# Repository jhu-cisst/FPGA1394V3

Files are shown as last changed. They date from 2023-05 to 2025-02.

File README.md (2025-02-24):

# FPGA1394V3
Design files for FPGA1394V3 board in Altium Designer format. The design files for the previous
revisions, Rev 1.x and and Rev 2.x, are in [this repository](https://github.com/jhu-cisst/FPGA1394).

The Rev 3.x design is based on the Xilinx Zynq System on Chip (SoC), XC7Z020, which includes an
FPGA (PL) and dual-core ARM processor (PS). The previous versions (Rev 1.x and 2.x) were based on
the Xilinx Spartan 6 FPGA. In addition, the Rev 3.x design contains two Ethernet ports, as compared
to one in Rev 2.x and none in Rev 1.x.

* `FPGA3.PrjPCB`: Altium Designer project file
* `Snn.SchDoc`: schematics (Altium Designer format)
* `FPGA3.PcbDoc`: PCB layout (Altium Designer format)
* `FPGA1394V3-Schematics.pdf`: PDF of schematics
* `FPGA1394V3-BOM.xlsx`: Bill of Materials (Microsoft Excel format)
* `Panel`: Subdirectory with panel design, including PCB fabrication and assembly files
 
## Release Notes

* Rev 3.0: Prototype design (3 boards built), design files not released
* Rev 3.1: Initial Release, Build #9 (107 boards)
* Rev 3.2: Minor updates, Build #10 (65 boards)
  * Removed L9-10 (previously, 0 Ohm resistors) for RTL8211F DC/DC converter
  * Added C77-78 for soft-start of 3.3V and 5V power supplies
  * Added test points on underside of board for manufacturing test
  * Reduced openings for center pads on top side paste mask

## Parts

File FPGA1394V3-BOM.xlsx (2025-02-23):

 | IEEE-1394/Ethernet FPGA Board, Rev 3.2
 | Bill Of Materials
 | 2024-11-13
Revision: |  | 3.2
Seq | Qty. | Ref Des | Description | Package | Manufacturer | Notes | Manufacturer Part # | Distributor | Distributor Part # | Avcon Part # | Est. Unit $ | Extended Cost
1 | 5 | C1-5 | CAP 22pF, 5%, 50V, NPO, 0402 | 0402 | Generic | 2
2 | 2 | C6-7 | CAP, 220pF, 5%, 50V, NPO, 0603 | 0603 | Generic | 2 | C0603C221J5GACTU | Digikey | 399-1066-1-ND | 022-2216-61/603 | 0.02 | 0.05
3 | 2 | C8-9 | CAP, 0.01uF, 10%, 16V, X7R, 0402 | 0402 | Generic | 2
4 | 21 | C10-30 | CAP, 0.1uF, 10%, 16V, X7R, 0402 | 0402 | Generic | 2 | GRM155R71C104KA88D
5 | 10 | C31-40 | CAP, 1.0uF, 10%, 10V, X7S, 0402 | 0402 | Generic | 2 | GCM155C71A105KE38D |  | 490-13409-1-ND
6 | 5 | C41-45 | CAP, 22uF, 20%, 25V, X5R, 0805 | 0805 | Murata | 2 | GRM21BR61E226ME44L |  | 490-10749-6-ND |  | 0.14 | 0.68
7 | 13 | C46-58 | CAP, 220uF, 20%, 4V, X6S, 1206 | 1206 | Murata | 2 | GRM31CC80G227ME11L |  | 490-13250-6-ND |  | 0.43 | 5.62
8 | 2 | C59-60 | CAP, 10uF, 20%, 50V, X7S, 1210 | 1210 | Murata | 2 | GCM32EC71H106KA03L |  | 490-14536-6-ND |  | 0.59 | 1.19
9 | 5 | C61-65 | CAP, 100uF, 20%, 10V, X5R, 1210 | 1210 | Samsung | 2 | CL32A107MPVNNNE | Digikey | 1276-3364-1-ND | 022-1071-81/121 | 0.65 | 3.24
10 | 2 | C66-67 | CAP, 220uF, 20%, 6.3V, X5R, 1210 | 1210 | Samsung | 2 | CL32A227MQVNNNE | Digikey | 1276-3375-1-ND | 022-2270-81/121 | 1.22 | 2.44
11 | 2 | C68-69 | CAP, 33uF 10%, 50V, Conductive Polymer "KO Cap" | CAP-D | Kemet | NS | T521X336M050ATE075 | Digikey | 399-11721-1-ND | 022-3366-81SM | 4.80 | 9.60
12 | 2 | C70-71 | CAP, 330uF 10%, 10V, Conductive Polymer "KO Cap" | CAP-D | Kemet | NS | T520Y337M010ATE015 | Digikey | 399-10362-1-ND | 022-3371-81SM | 3.24 | 6.48
13 | 2 | C72-73 | CAP, 470uF 10%, 6.3V, Conductive Polymer "KO Cap" | CAP-D | Kemet | NS | T520D477M006ATE025 | Digikey | 399-4985-1-ND | 022-4770-71SMD | 1.35 | 2.70
14 | 1 | C74 | CAP, 680uF 10%, 2.5V, Conductive Polymer "KO Cap" | CAP-D | Kemet | NS | T520D687M2R5ATE015 | Digikey | 399-4065-1-ND | 022-6870-81SMD | 1.31 | 1.31
15 | 2 | C75-76 | CAP, 1000uF, 20%, 2.5V, 5mOhm | CAP-D | Panasonic | 2 | ETPF1000M5H |  | P16642DKR-ND |  | 2.38 | 4.75
16 | 2 | C77-78 | CAP, 4700pF, 10%, 16V, X7R, 0402 | 0402 | Generic | 2
17 | 75 | CB1-75 | CAP, 0.1uF, 20%, 6.3V, X6S, 0201 | 0201 | Generic | 2 | GRM033C80J104KE15D |  | 490-10390-6-ND
18 | 40 | CB76-115 | CAP, 0.47uF, 20%, 16V, X7R, 0402 | 0402 | Generic | 2 | GCM155C71A474KE36D |  | 490-14427-1-ND
19 | 25 | CB116-140 | CAP, 10uF, 20%, 16V, X6S, 0603 | 0603 |  | 2 | GRM188C81C106MA73D |  | 490-7198-6-ND |  | 0.07 | 1.82
20 | 1 | D1 | TVS, 16V Bidirectional, SMCJ16C | DIODE-SMC |  | 2 | SMCJ16CA |  | SMCJ16CALFCT-ND |  | 0.41 | 0.41
21 | 3 | D2-4 | LED, Green, RA, 0805 | 0805 | Broadcom | 2 | HSME-C170 | Digikey | 516-3542-1-ND | 024-6176-805 | 0.32 | 0.95
22 | 8 | D5-12 | DIODE, BAV99T, Dual/Serial, 70V, 85mA | SOT-523 | Diodes Inc. | 2 | BAV99T-7-F | Digikey | BAV99T-FDICT-ND | 024-0118-SM | 0.04 | 0.34
23 | 2 | J1-2 | CONN, Socket, 2x22 Pos, Vertical, 2MM | TH | Samtec | 2 | ESQT-122-02-L-D-560 | Samtec | ESQT-122-02-L-D-560 | 026-0844-00 | 5.72 | 11.44
24 | 2 | J3-4 | CONN, IEEE-1394, 6-Pin, R/A | Firewire6-RA | 3M | NS, 4 | 3E106-2230KV | Digikey | 3M9423-ND | 026-1139-00 | 3.34 | 6.69
25 | 1 | J5 | CONN, MicroSDCARD, ST12S010 | SM | JAE | NS | ST12S010VBAR1800 |  | 670-3034-1-ND |  | 2.12 | 2.12
26 | 1 | J6 | CONN, Header, 2 Pos, Vertical 0.100 | HDR-2x1-100 | Tyco | 2 | 640456-2 | Digikey | A1921-ND | 026-0080-00 | 0.09 | 0.09
27 | 1 | J7 | CONN, Header, 2x7 Pos, Vertical, Polarized, 2MM | HDR-7x2-2MM | FCI | 2 | 98414-G06-14LF | Digikey | 609-2576-ND | 026-0847-00
28 | 1 | J8 | CONN, Dual RJ-45 With Transformer 10/100/1000 | TH | Pulse |  | JXD0-2015NL | Digikey | 1840-1011-ND |  | 11.40 | 11.40
29 | 1 | J9 | CONN, RA, DF-11, 6-pin | DF-11-6-RA | Hirose |  | DF11-6DP-2DS(24) | Digikey | H10245-ND |  | 0.43 | 0.43
30 | 1 | J10 | CONN, Header, 6 Pos, Vert 0.1" pitch, 0.23" - 0.318" ht | HDR-6x1-100 | AMP | 2 | 5-146280-6 | Digikey | A121372-ND | 029-0507-06 |  | 0.00
31 | 1 | L1 | INDUCTOR, 1.5uH, 13A, XGL5050 | XGL5050 | Coilcraft | NS | XGL5050-152MEC |  |  |  | 2.26 | 2.26
32 | 1 | L2 | INDUCTOR, 1.2uH, 15A, XGL5050 | XGL5050 | Coilcraft | NS | XGL5050-122MEC |  |  |  | 2.26 | 2.26
33 | 1 | L3 | INDUCTOR, 0.68uH, 10A, XGL4040 | XGL4040 | Coilcraft | NS | XGL4040-681MEC |  |  |  | 1.79 | 1.79
34 | 2 | L4-5 | INDUCTOR, 1.5uH, 8A, XGL4040 | XGL4040 | Coilcraft | NS | XGL4040-152MEC |  |  |  | 1.34 | 2.68
35 | 2 | L6-7 | INDUCTOR, 3.3uH, 0.9A, EPL2014 | EPL2014 | Coilcraft | NS | EPL2014-332MLC |  |  |  | 0.26 | 0.52
36 | 1 | L8 | FERRITE, 500mA, 150mOhm, 600 Ohm @ 100MHz | 0603 | Murata | 2 | BLM18KG601BH1D | Digikey | 490-14032-1-ND |  | 0.04 | 0.04
37 | 4 | L11-14 | FERRITE BEAD, 2A, 50mOhm, 120 Ohm @ 100MHz | 0402 | Murata | 2 | BLM15PX121SN1D | Digikey | 490-9656-1-ND |  | 0.03 | 0.11
38 | 2 | L15-16 | FERRITE BEAD, 50 Ohm/10 mOhm, 6A | 1206 | Laird | 2 | HI1206T500R-10 | Digikey | 240-2412-1-ND | 023-0431-1206 | 0.06 | 0.11
39 | 2 | Q1-2 | MOSFET, N-Chan, 20V, Si7108 | PowerPack-1212 | Vishay | 2 | SI7108DN-T1-GE3 | Digikey | SI7108DN-T1-GE3CT-ND | 024-2189-SM | 1.40 | 2.81
40 | 1 | Q3 | MOSFET, P-Chan, 40V, Si7611 | PowerPack-1212 | Vishay | 2 | SI7611DN-T1-GE3 | Digikey | SI7611DN-T1-GE3CT-ND | 024-2193-SM | 0.70 | 0.70
41 | 2 | Q4-5 | MOSFET, Dual N-Chan, 20V 250mA | SC70-6 | NXP | 2 | PMG370XN,115 |  |  | 024-2190-SM | 0.07 | 0.13
42 | 1 | Q6 | TRANSISTOR, PNP, 1A, 20V, DCX69-16 | SOT-89 | Diodes Inc. | 2 | DCX69-16-13 | Digikey | DCX69-16DICT-ND | 024-1036-SM | 0.35 | 0.35
43 | 8 | R1-8 | RES, 49.9 Ohm, 1%, 1/20W, 0201 | 0201 | Generic | 2
44 | 1 | R9 | RES, 4.99, 1% 1/16W | 0402 | Generic | 2
45 | 23 | R10-32 | RES, 40.2, 1% 1/16W | 0402 | Generic | 2
46 | 3 | R33-35 | RES, 80.6, 1% 1/16W | 0402 | Generic | 2
47 | 4 | R36-39 | RES, 100, 1% 1/16W | 0402 | Generic | 2
48 | 6 | R40-45 | RES, 240, 1% 1/16W | 0402 | Generic | 2
49 | 10 | R46-55 | RES, 499, 1% 1/16W | 0402 | Generic | 2
50 | 5 | R56-60 | RES, 1.00K, 1% 1/16W | 0402 | Generic | 2
51 | 0 | R60A | Do Not Install | 0402 |  | 3
52 | 4 | R61-64 | RES, 1.50K, 1% 1/16W | 0402 | Generic | 2
53 | 2 | R65-66 | RES, 2.49K, 1% 1/16W | 0402 | Generic | 2
54 | 11 | R67-77 | RES, 4.99K, 1% 1/16W | 0402 | Generic | 2
55 | 2 | R78-79 | RES, 6.34K, 1% 1/16W | 0402 | Generic | 2
56 | 2 | R80-81 | RES, 13.3K, 1% 1/16W | 0402 | Generic | 2
57 | 11 | R82-92 | RES, 20.0K, 1% 1/16W | 0402 | Generic | 2
58 | 1 | R93 | RES, 31.6K, 1% 1/16W | 0402 | Generic | 2
59 | 1 | R94 | RES, 162K, 1% 1/16W | 0402 | Generic | 2
60 | 2 | R95-96 | RES, 301K, 1% 1/16W | 0402 | Generic | 2
61 | 1 | R97 | RES, 22.1K, 0.1%, 1/16W, 0402 | 0402 |  | 2 | CPF-A-0402B22K1E |  | 1712-CPF-A-0402B22K1ECT-ND |  | 0.21 | 0.21
62 | 7 | R98-104 | RES, 100K, 0.1%, 1/16W, 0402 | 0402 |  | 2 | CPF0402B100KE |  | A119916CT-ND |  | 0.12 | 0.82
63 | 1 | R105 | RES, 115K, 0.1%, 1/16W, 0402 | 0402 |  | 2 | RP73PF1E115KBTD |  | A127517CT-ND |  | 0.62 | 0.62
64 | 2 | R106-107 | RES, 150K, 0.1%, 1/16W, 0402 | 0402 |  | 2 | CPF0402B150KE |  | A119924CT-ND |  | 0.20 | 0.41
65 | 1 | R108 | RES, 200K, 0.1%, 1/16W, 0402 | 0402 |  | 2 | CPF0402B200KE |  | A119933CT-ND |  | 0.20 | 0.20
66 | 8 | R109-116 | RES, 56.0, 0.5%, 1/10W, 0603 | 0603 | Susumu | 2 | RR0816Q-560-D | Digikey | RR08Q56DCT-ND | 020-5607-41/603 | 0.02 | 0.19
67 | 2 | R117-118 | RES, 0.015, 1%, 1/2W, 1206 | 1206 |  | 2 | CSR1206FK15L0 | Digikey | CSR1206FK15L0CT-ND |  | 0.23 | 0.47
68 | 2 | RN1-2 | RES ARRAY, 4.7K, 4 DIS, 5%, SM 0.032 | R-SM-8/32 | CTS | 2 | 742C083472JPTR | Digikey | 742C083472JPCT-ND | 020-4701-61RA | 0.06 | 0.12
69 | 1 | SW1 | SWITCH, Rotary, Hex | TH | Grayhill | 2 | 94HAB16T | Digikey | GH7255-ND | 029-0458-00 | 2.48 | 2.48
70 | 1 | U1 | IS, SOC, XC7Z020-CLG400 | BGA-400-08mm | Xilinx | 5 | XC7Z020-sCLG400t | Digikey | 122-1848-ND |  | 180.70 | 180.70
71 | 2 | U2-3 | IC, DRAM, 256M x 16, MT41K256M16 | BGA-96-14x8mm | Micron | NS | MT41K256M16TW-107:P | Digikey | 557-1792-ND |  | 8.64 | 17.29
72 | 1 | U4 | IC, 128MBit Quad SPI Flash PROM, W25Q128JVSIQ | SOL-8 | Winbond | NS | W25Q128JVSIQ |  | W25Q128JVSIQ-ND |  | 1.48 | 1.48
73 | 1 | U5 | IC, IEEE-1394 Physical Layer, TSB41AB2 | PQFP-65 | TI |  | TSB41AB2PAP | Digikey | 296-11076-ND | 024-9309-SM | 5.55 | 5.55
74 | 1 | U6 | IC, Shunt Regulator, 1.24V, 70mA, TLVH431 | SC70-6 | TI |  | TLVH431ACDCKT | Digikey | 296-32425-1 | 024-2415-SM | 0.68 | 0.68
75 | 1 | U7 | IC, Oscillator, 24.576MHz, 50PPM, 3.3V | OSC-3x5MM | AVX | 2 | KC5032A24.5760CM0E00 | Digikey | 1253-1042-1-ND | 029-0459-SM | 1.31 | 1.31
76 | 1 | U8 | IC, Bidirectional Voltage Translator, TXS0101 | SC70-6 | TI | 2 | TXS0101DCK | Digikey | 296-22864-1-ND |  | 0.27 | 0.27
77 | 1 | U9 | IC, Dual Buffer, 74AUP2G17 | SC70-6 | NXP | 2 | 74AUP2G17GW,125 | Digikey | 1727-6878-1-ND |  | 0.22 | 0.22
78 | 2 | U10-11 | IC, Ethernet PHY, RTL8211F | QFN-40-5MM | Realtek |  | RTL8211F-CG |  |  |  | 3.59 | 7.18
79 | 2 | U12-13 | IC, Hot Swap Controller with retry, LTC4210-1 | SOT-23-6 | Linear Tech | 1 | LTC4210-1CS6#PBF | Linear Tech | LTC4210-1CS6#PBF | 024-3782-SM | 3.39 | 6.78
80 | 1 | U14 | IC, 4 Phase Spread Spectrum Clock, LTC6902 | MSOP-10 | Linear Tech | 1 | LTC6902CMS#TRPBFCT | Linear Tech | LTC6902CMS#TRPBFCT | 024-2754-SM | 4.28 | 4.28
81 | 1 | U15 | IC, Quad Step-Down DC-DC Converter, LTC3644 | BGA-36-08mm | Linear Tech | 1 | LTC3644EY#PBF | Digikey | 161-LTC3644EY#PBF-ND |  | 5.62 | 5.62
82 | 1 | U16 | IC, Dual Step-Down DC-DC Converter, LTC3636 | QFN-28-LTC3636 | Linear Tech | 1 | LTC3636IUFD-1#PBF | Digikey | LTC3636IUFD-1#PBF-ND |  | 8.86 | 8.86
83 | 1 | U17 | IC, Quad Voltage Monitor, LTC2908-B1 | SOT-23-8 | Linear Tech | 1 | LTC2908CTS8-B1#TRMPBF |  | LTC2908CTS8-B1#TRMPBFCT-ND |  | 5.09 | 5.09
84 | 1 | U18 | IC, DDR Termination Power Supply, LP2998 | SO-8 | TI |  | LP2998QMRX/NOPB | Digikey | 296-49242-1-ND |  | 1.46 | 1.46
85 | 1 | U19 | IC, Crystal Oscillator, 25.00MHz | OSC-2x2.5mm | ECS | 2 | ECS-2520MVQ-250-BP-TR | Digikey | 50-ECS-2520MVQ-250-BP-CT-ND | 024-9372-SM | 1.11 | 1.11
86 | 1 | U20 | IC, Crystal Oscillator, 33.33MHz | OSC-2x2.5mm | Abracon | 2 | ASDDV-33.3333MHZ-LC-T |  | 535-ASDDV-33.3333MHZ-LC-TCT |  | 1.16 | 1.16
87 | 1 |  | PCB, IEEE-1394/Ethernet FPGA Controller, Rev 3.1 |  |  |  |  |  |  |  | 25.00 | 25.00
 | 402 |  |  |  |  |  |  |  |  | Estimated Total Cost: |  | $367.07
Notes:
 | ● | Text highlighted in red is highlighted to draw attention to the value/parameter and does not carry any special meaning.
 | ● | Component prices shown are the best guess at the time of updating this BOM, assuming Qty ~100 boards. Actual prices may be higher or lower depending upon a number of factors.
 | ● | Unless specified otherwise, the only substitutions allowed are substituting identical part number parts from a different manufacturer.
 | NS | No substitutions of any kind are allowed.
 | 1 | For Linear Tech parts, it is acceptable to substitute I (industrial temp), E (extended temp) or H (high temp) rated parts.
 |  | The suffixes "TRM" and "TR" signify tape and reel styles. Parts with suffix TRM, suffix TR can be substituted as needed.
 |  | Other than as specified above, no other substitutions are allowed.
 | 2 | Any component in an identical package that meets or exceeds all the parameters specified in the description can be substituted.
 | 3 | Either R60 or R60A can be installed.
 | 4 | Another approved part is TE Connectivity AMP 5787956-1 (Digikey P/N A114040-ND)
 | 5 | XC7Z020-sCLG400t, where s (speed grade) can be 2 or 3 and t (temperature grade) can be C, I or E

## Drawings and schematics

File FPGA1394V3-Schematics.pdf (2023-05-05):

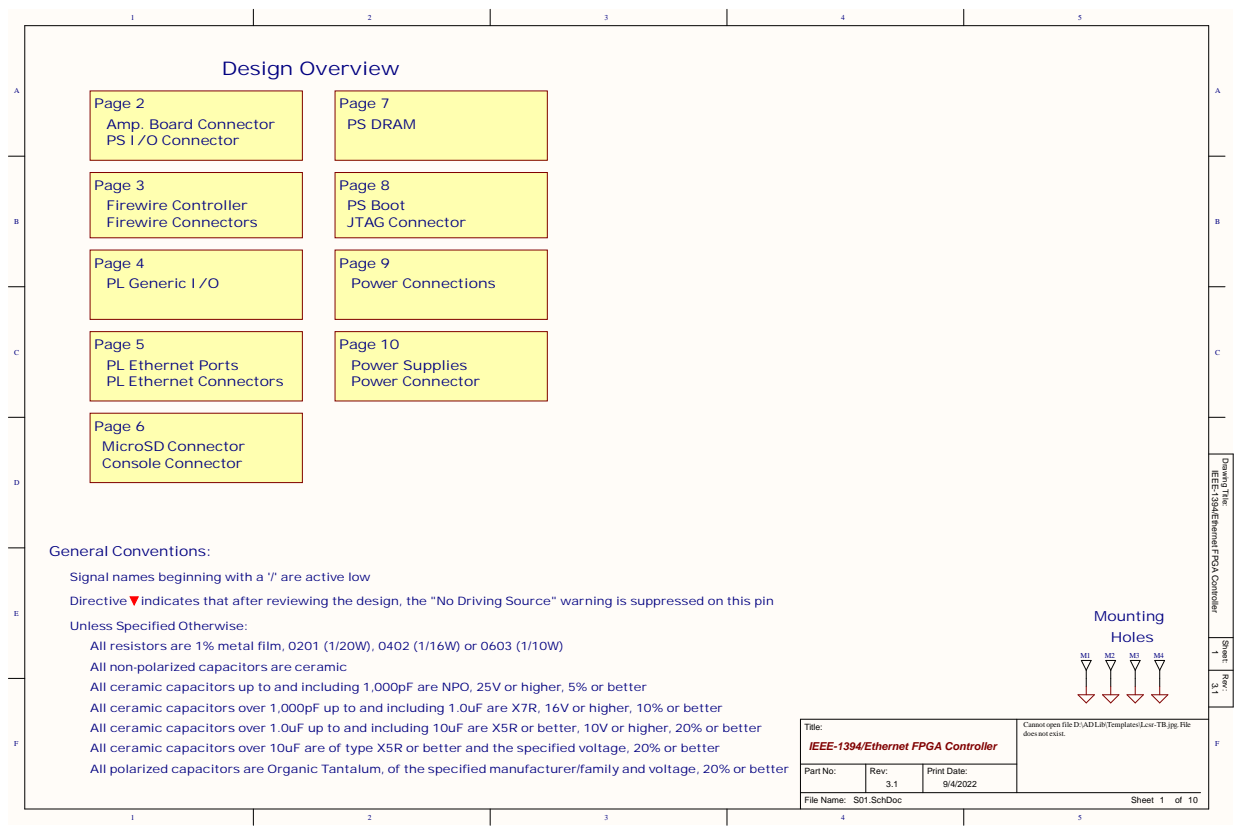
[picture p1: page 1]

Drawing Title: Rev: Sheet:

1 IEEE-1394/Ethernet FPGA Controller 3.1

Title: IEEE-1394/E thernet FP GA Controller | Sheet 1 o f 10

File Name: S01. | S chDoc

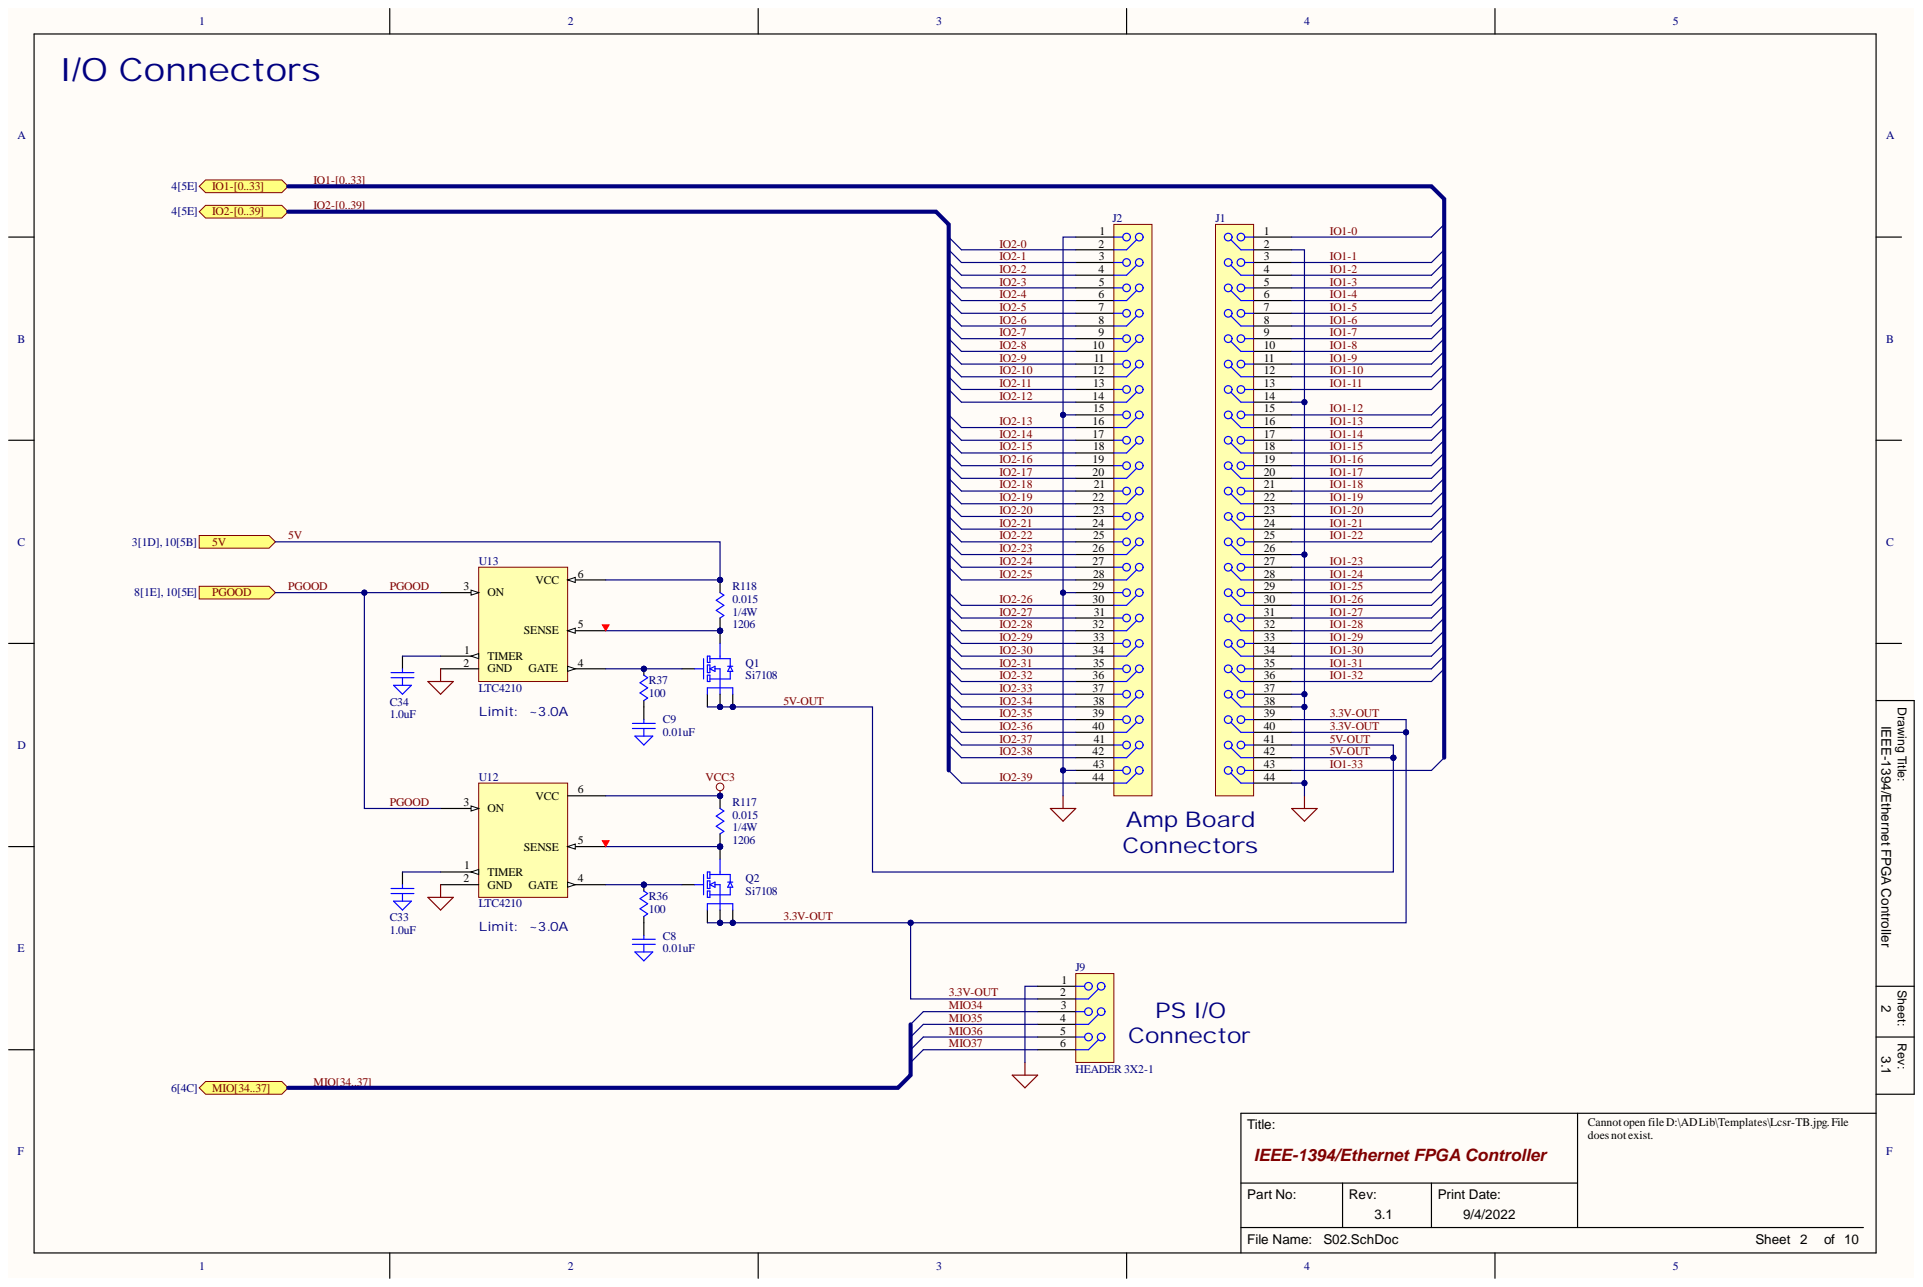
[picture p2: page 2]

Drawing Title: Rev: Sheet:

40 | 3.3V-OUT
41 | 5V-OUT
42 | | 5V-OUT
43 | | IO1-33
44

2 IEEE-1394/Ethernet FPGA Controller 3.1

Cannot open file D:\ADLib\Templates\Lcsr-TB.jpg. File
does not exist.

Title: IEEE-1394/Ethernet FPGA Controller | Sheet 2 of 10

File Name: S02.SchDoc

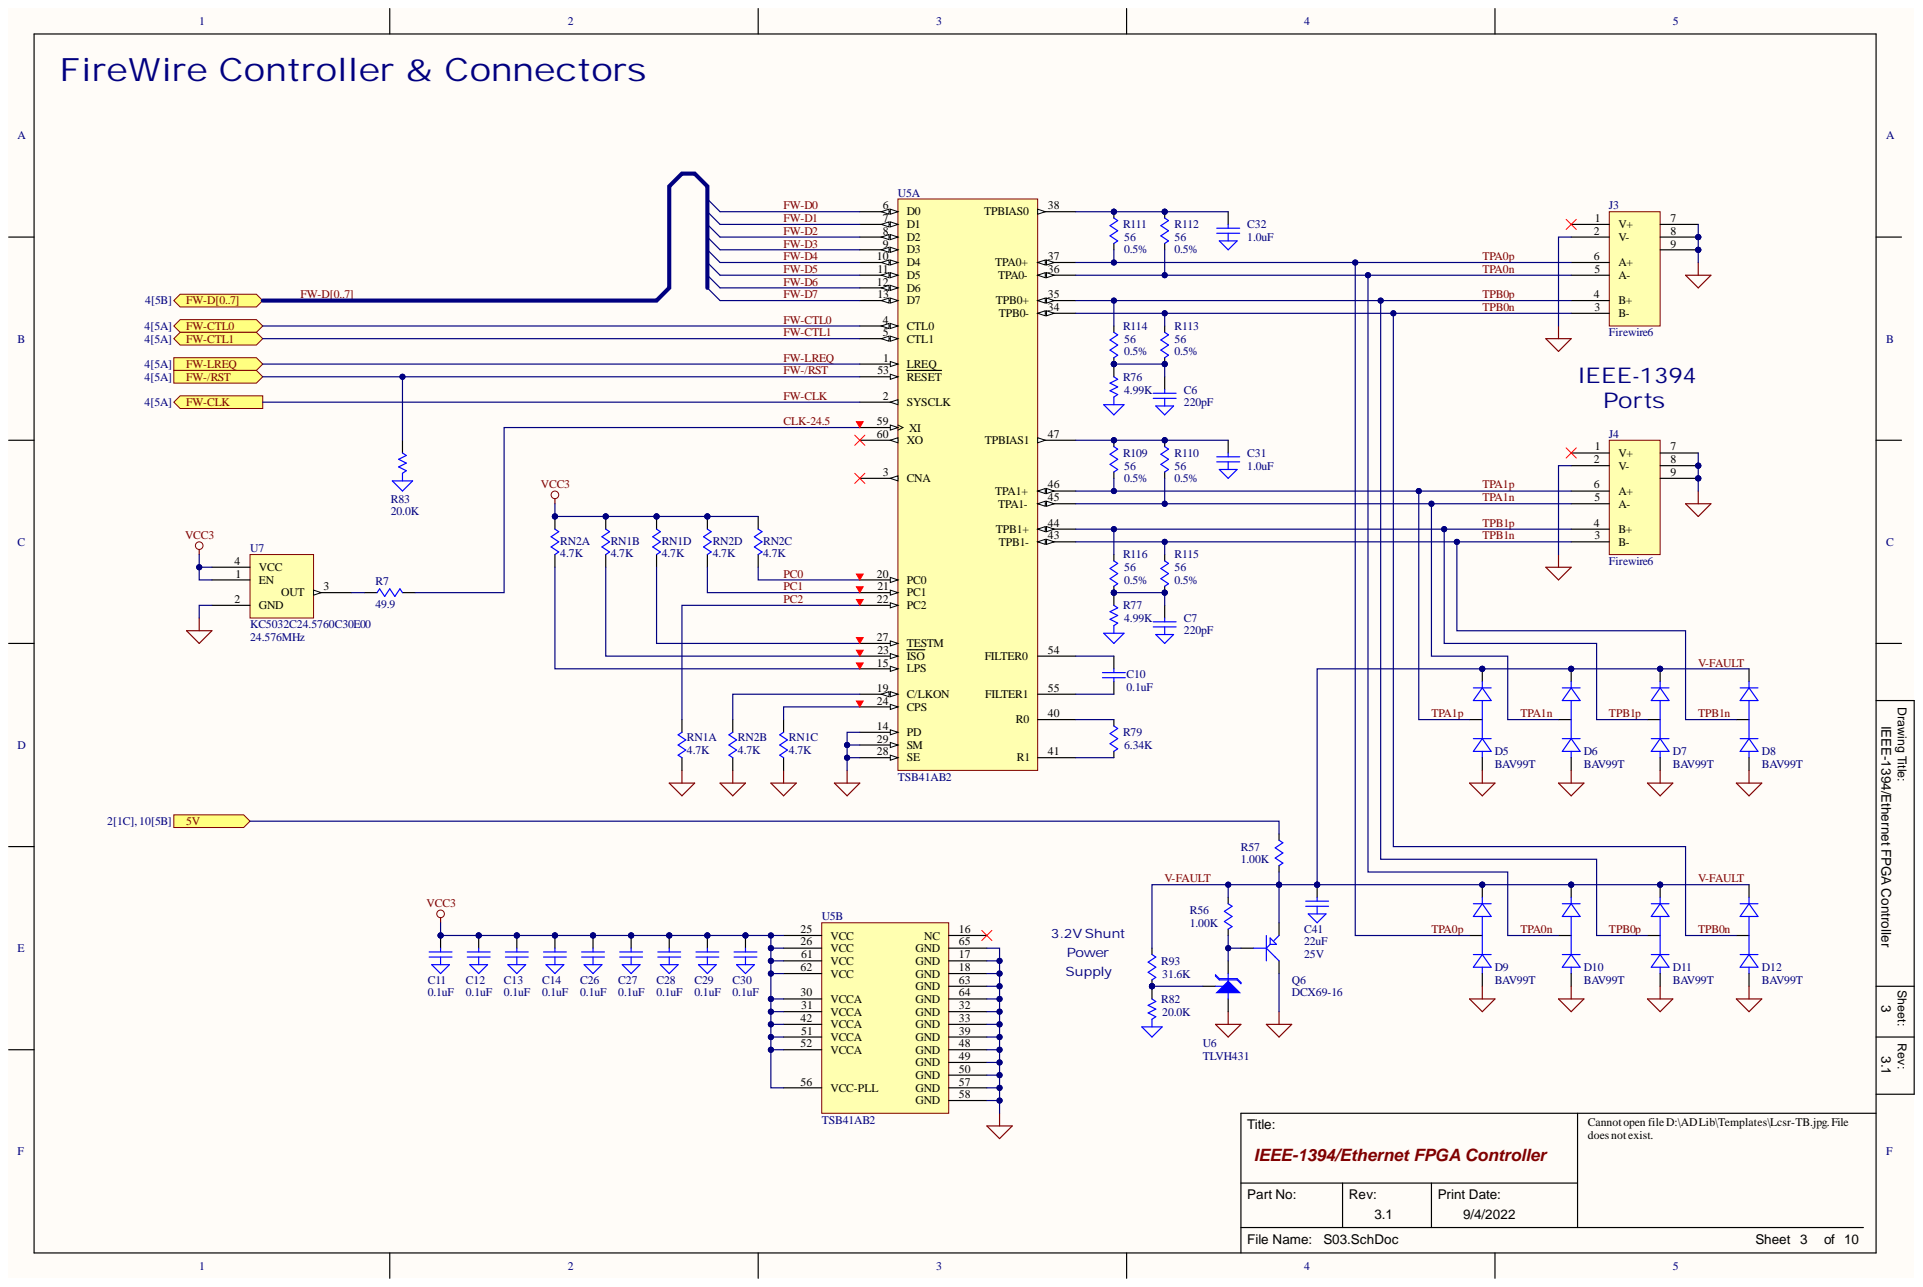
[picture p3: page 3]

TPB 0p | 4
TPB 0n | 3 | B + B -

TPB 1 p | 4
TPB 1 n | 3 | B -

Drawing Title: Rev: Sheet:

3 IEEE-1394/Ethernet FPGA Controller 3.1

Title: IEEE-1394/E thernet FP GA Controller | Sheet 3 o f 10

File Name: S03. | S chDoc

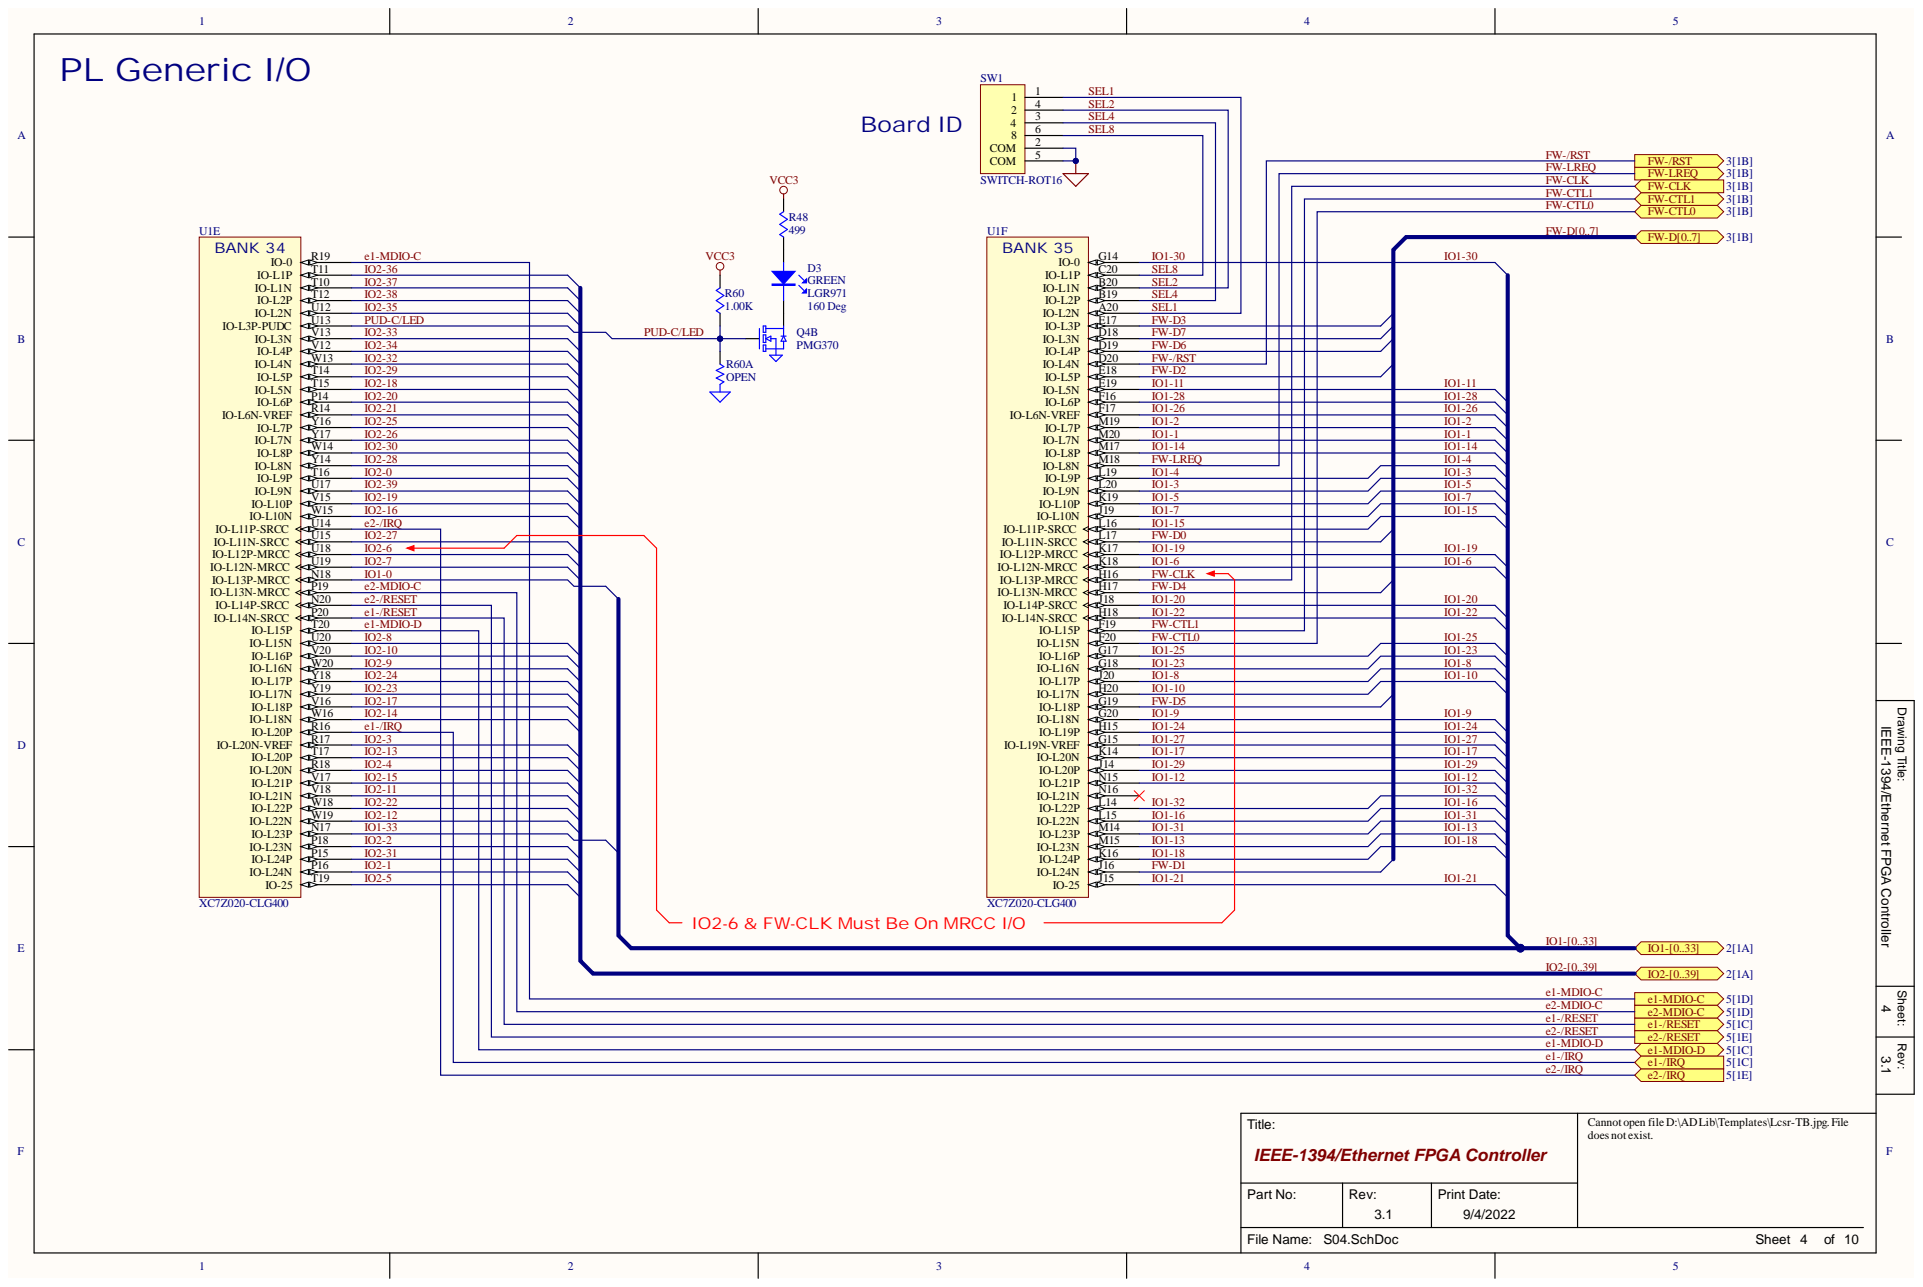
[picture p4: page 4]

4 | SE L 2
3 | SE L

FW -C T L 1
FW -C T L0

BANK 35 | O -0

T 1 1 T10 T12 U12 U13 | R60A OPEN I O2-29 I O2-18 I O2-20 I O2-21 I O2-25 I O2-26 I O2-30 I O2-28 I O2-0 I O2-39 I O2-19 I O2-16 e2-/ I RQ | I O -I O -I O -I O -I O -I O -I O -I O -L6N -V I O -I O -I O -I O -I O -I O -I O -I O -I O -L 11P-SR | L1P | C20 | SE L 8

L1N | B20 | SE L 2
L2P | A20 | SE L 1

N20 | e2-/ R E S ET | I O -L14P-SR CC | J 1 8 | I O1-20 | I O1-20
0 | e1-/ R E S ET | I O -L14N -SR CC | H18 | I O1-22 | I O1-22
T20 | e1-M D I O -D | L15P I O - | F1 9 | FW -C T L 1
U20 V20 0 Y18 Y19 V16 6 R16 | I O2-8 I O2-10 I O2-9 I O2-24 I O2-23 I O2-17 I O2-14 e1-/ I RQ | L15N I O -I O -L16P I O -L16N I O -L17P I O -L17N I O -L18P I O -L18N I O -L19P | F2 0 | FW -C T L0 | I O1-25

Drawing Title: Rev: Sheet:

4 IEEE-1394/Ethernet FPGA Controller 3.1

Title: IEEE-1394/E thernet FP GA Controller | Sheet 4 o f 10

File Name: S04. | S chDoc

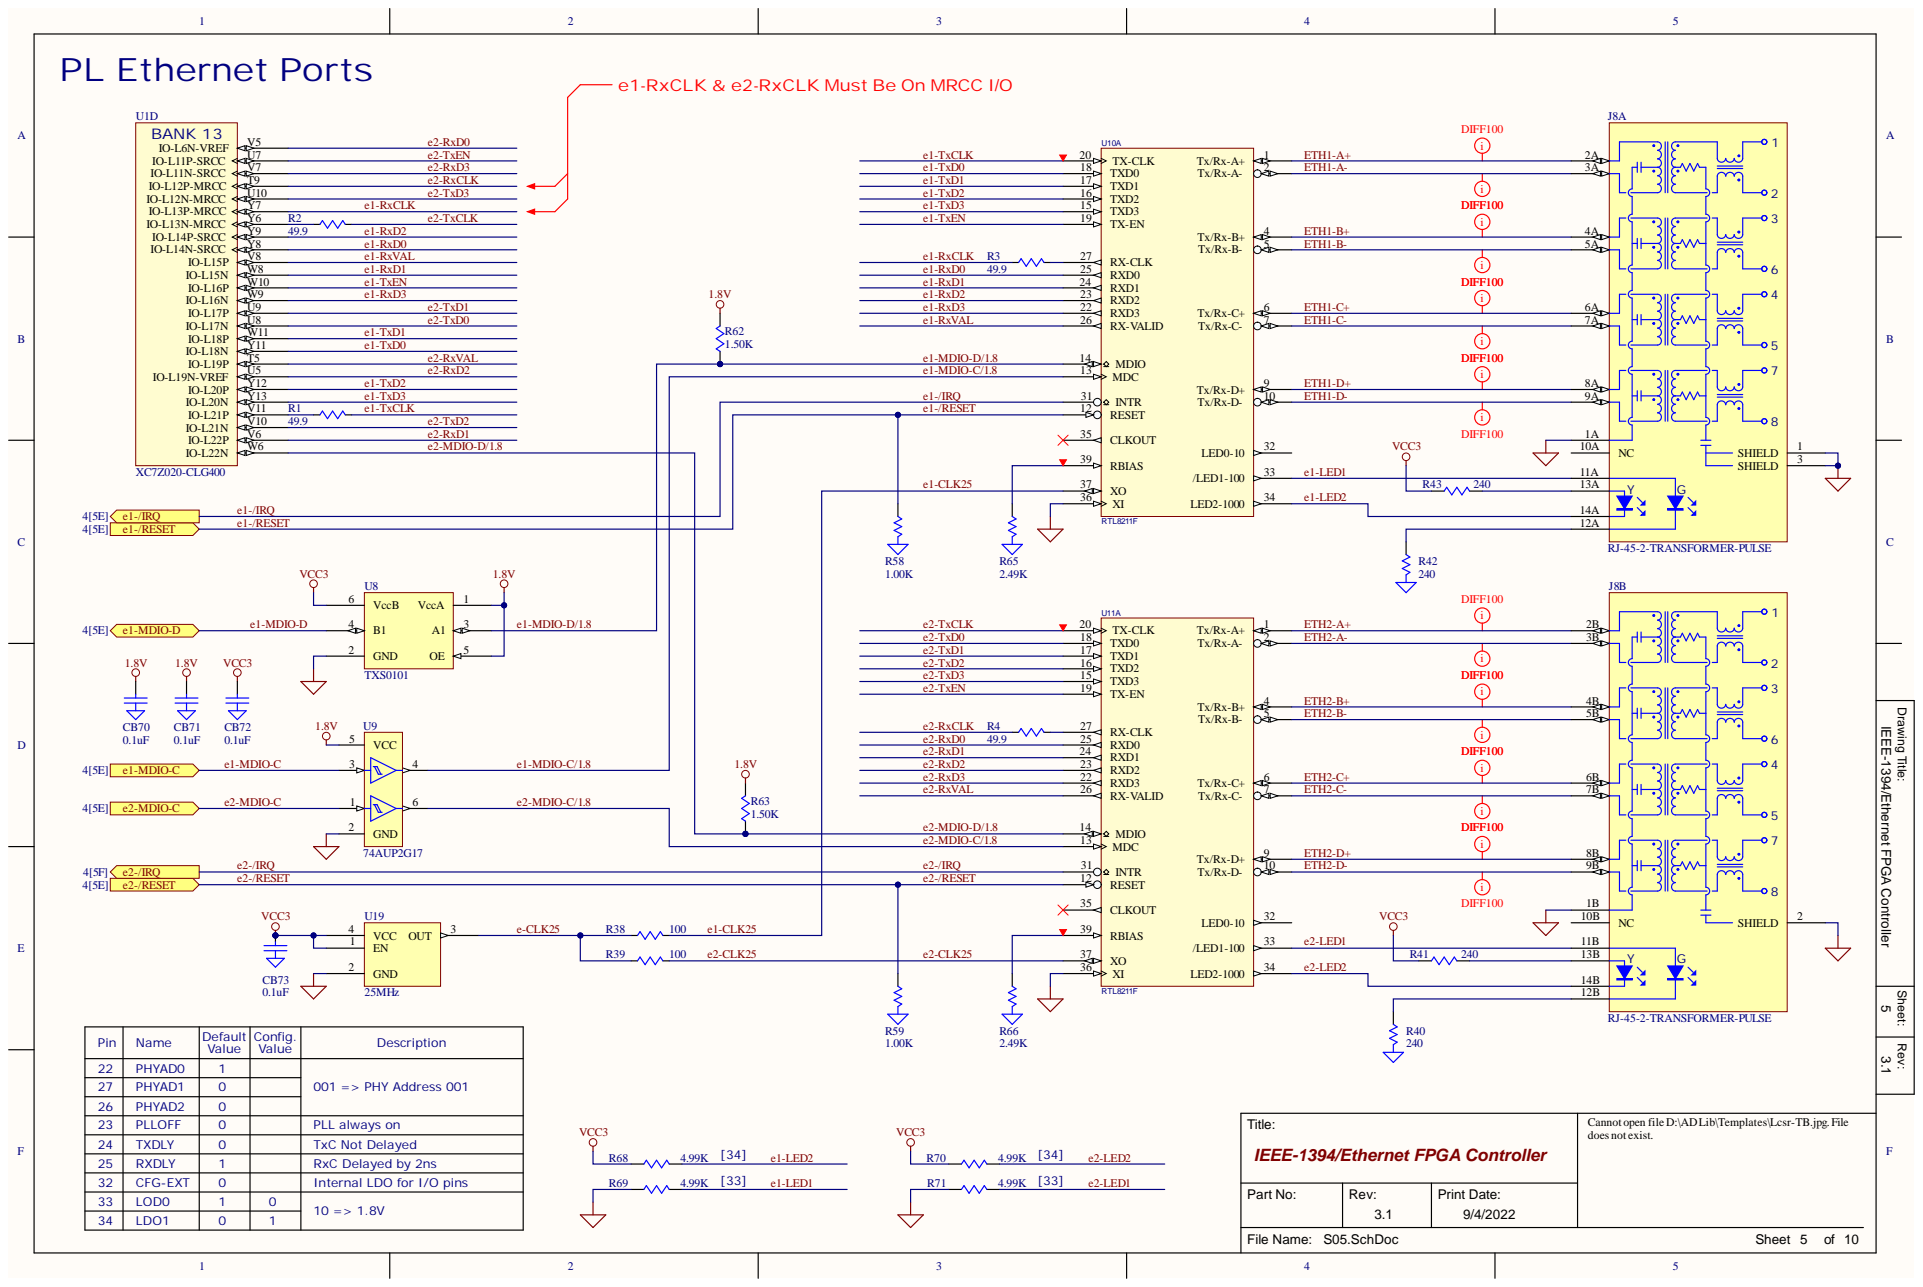
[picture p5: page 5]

e1-RxCLK & e2-RxCLK Must Be On MRCC I/O

XO 37
XI 36

e1-LED2

e1-/RESET | | | | | | 12A

VCC3 U8 | | 1.8V | R58 R65 1.00K 2.49K e2-TxCLK

VccA | A1 | 1 VccB 6 3 B1 4

Drawing Title: Rev: Sheet:

5 IEEE-1394/Ethernet FPGA Controller 3.1

R39 | 100 e2-CLK25 | e2-CLK25 | XO 37

Pin | Name | Default Value | Config. Value | Description

22 | PHYAD0 | 1 | | 001 => PHY Address 001
27 | PHYAD1 | 0
26 | PHYAD2 | 0

Cannot open file D:\ADLib\Templates\Lcsr-TB.jpg. File
does not exist.

Title:
IEEE-1394/Ethernet FPGA Controller

24 | TXDLY | 0 | | TxC Not Delayed
25 | RXDLY | 1 | | RxC Delayed by 2ns
32 | CFG-EXT | 0 | | Internal LDO for I/O pins
33 | LOD0 | 1 | 0 | 10 => 1.8V
34 | LDO1 | 0 | 1

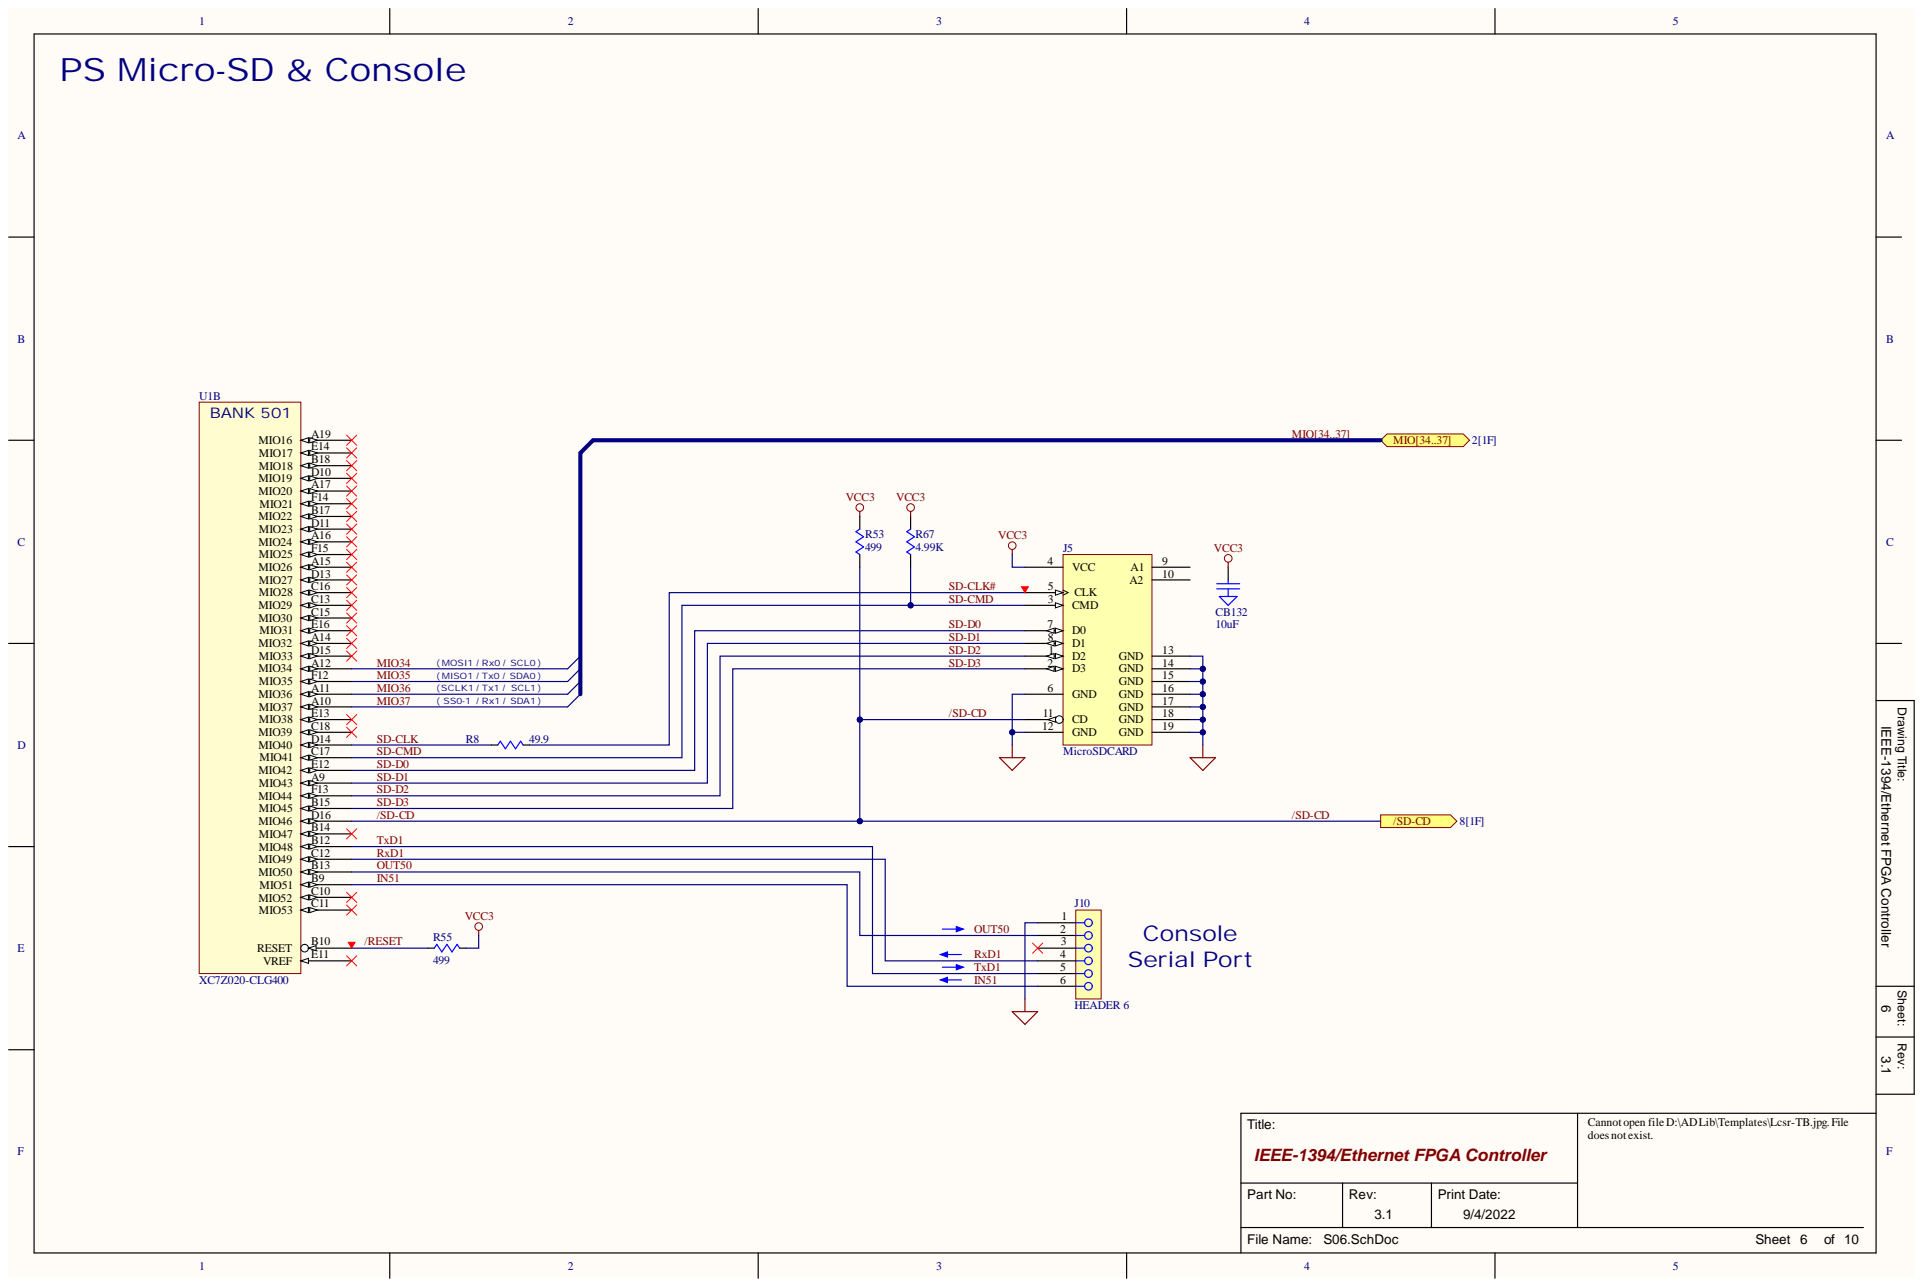
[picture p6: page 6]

SD -D0 | 7
SD -D 1 | 8
SD -D2 | 1

Drawing Title: Rev: Sheet:

6 IEEE-1394/Ethernet FPGA Controller 3.1

SD -D0
SD -D 1
SD -D2
SD -D 3

RxD 1
O U T50

RxD 1 | 123456

Title: IEEE-1394/E thernet FP GA Controller | Sheet 6 o f 10

File Name: S06. | S chDoc

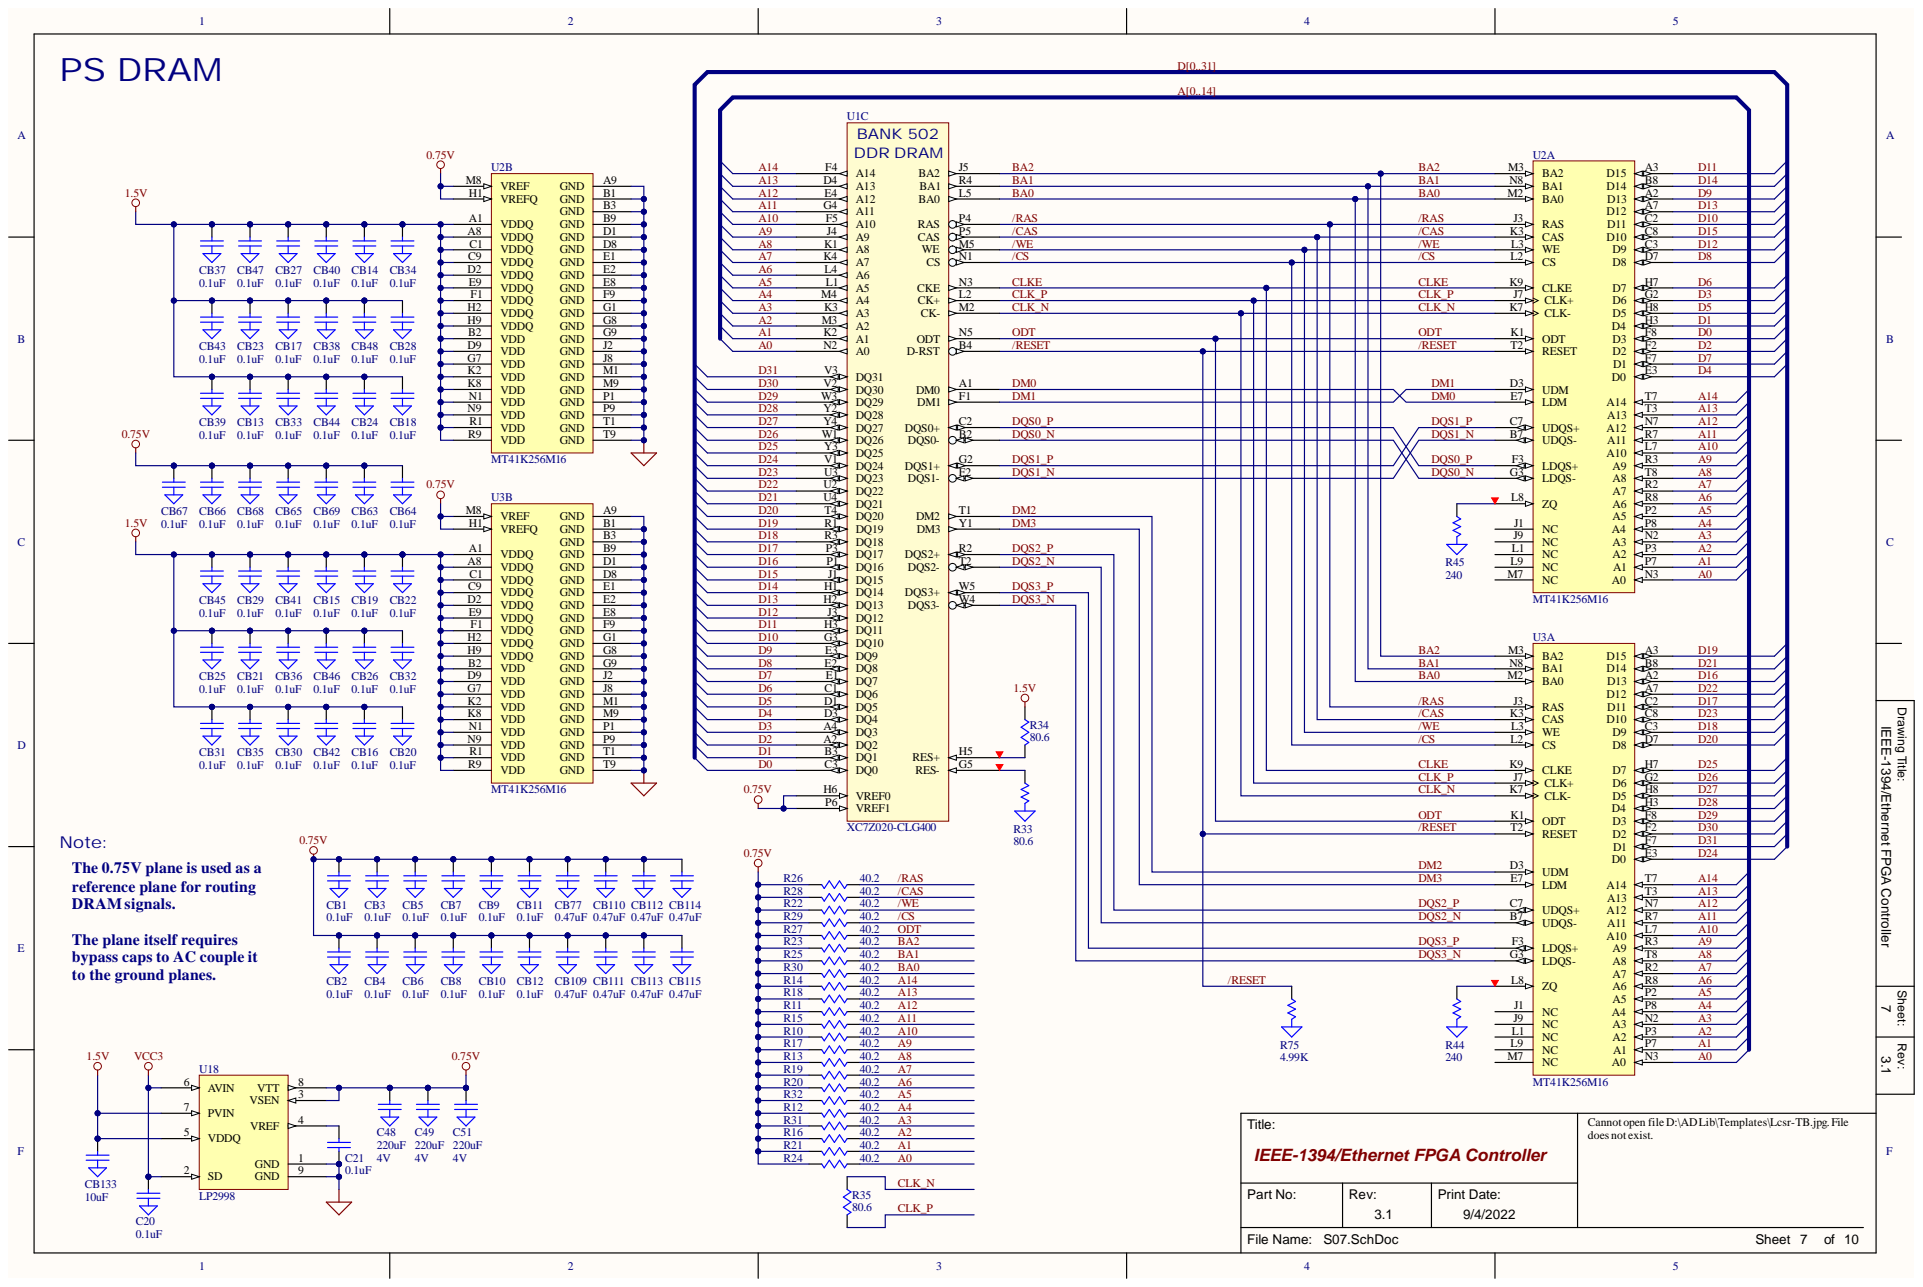
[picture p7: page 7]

K 2 | M 1
K 8 | M 9

R 1 | T 1
R 9 | T 9

Drawing Title: Rev: Sheet:

7 IEEE-1394/Ethernet FPGA Controller 3.1

D M 2 | D 3
D M 3 | E 7

ane itself requires
The pl
bypa
to the ground pl

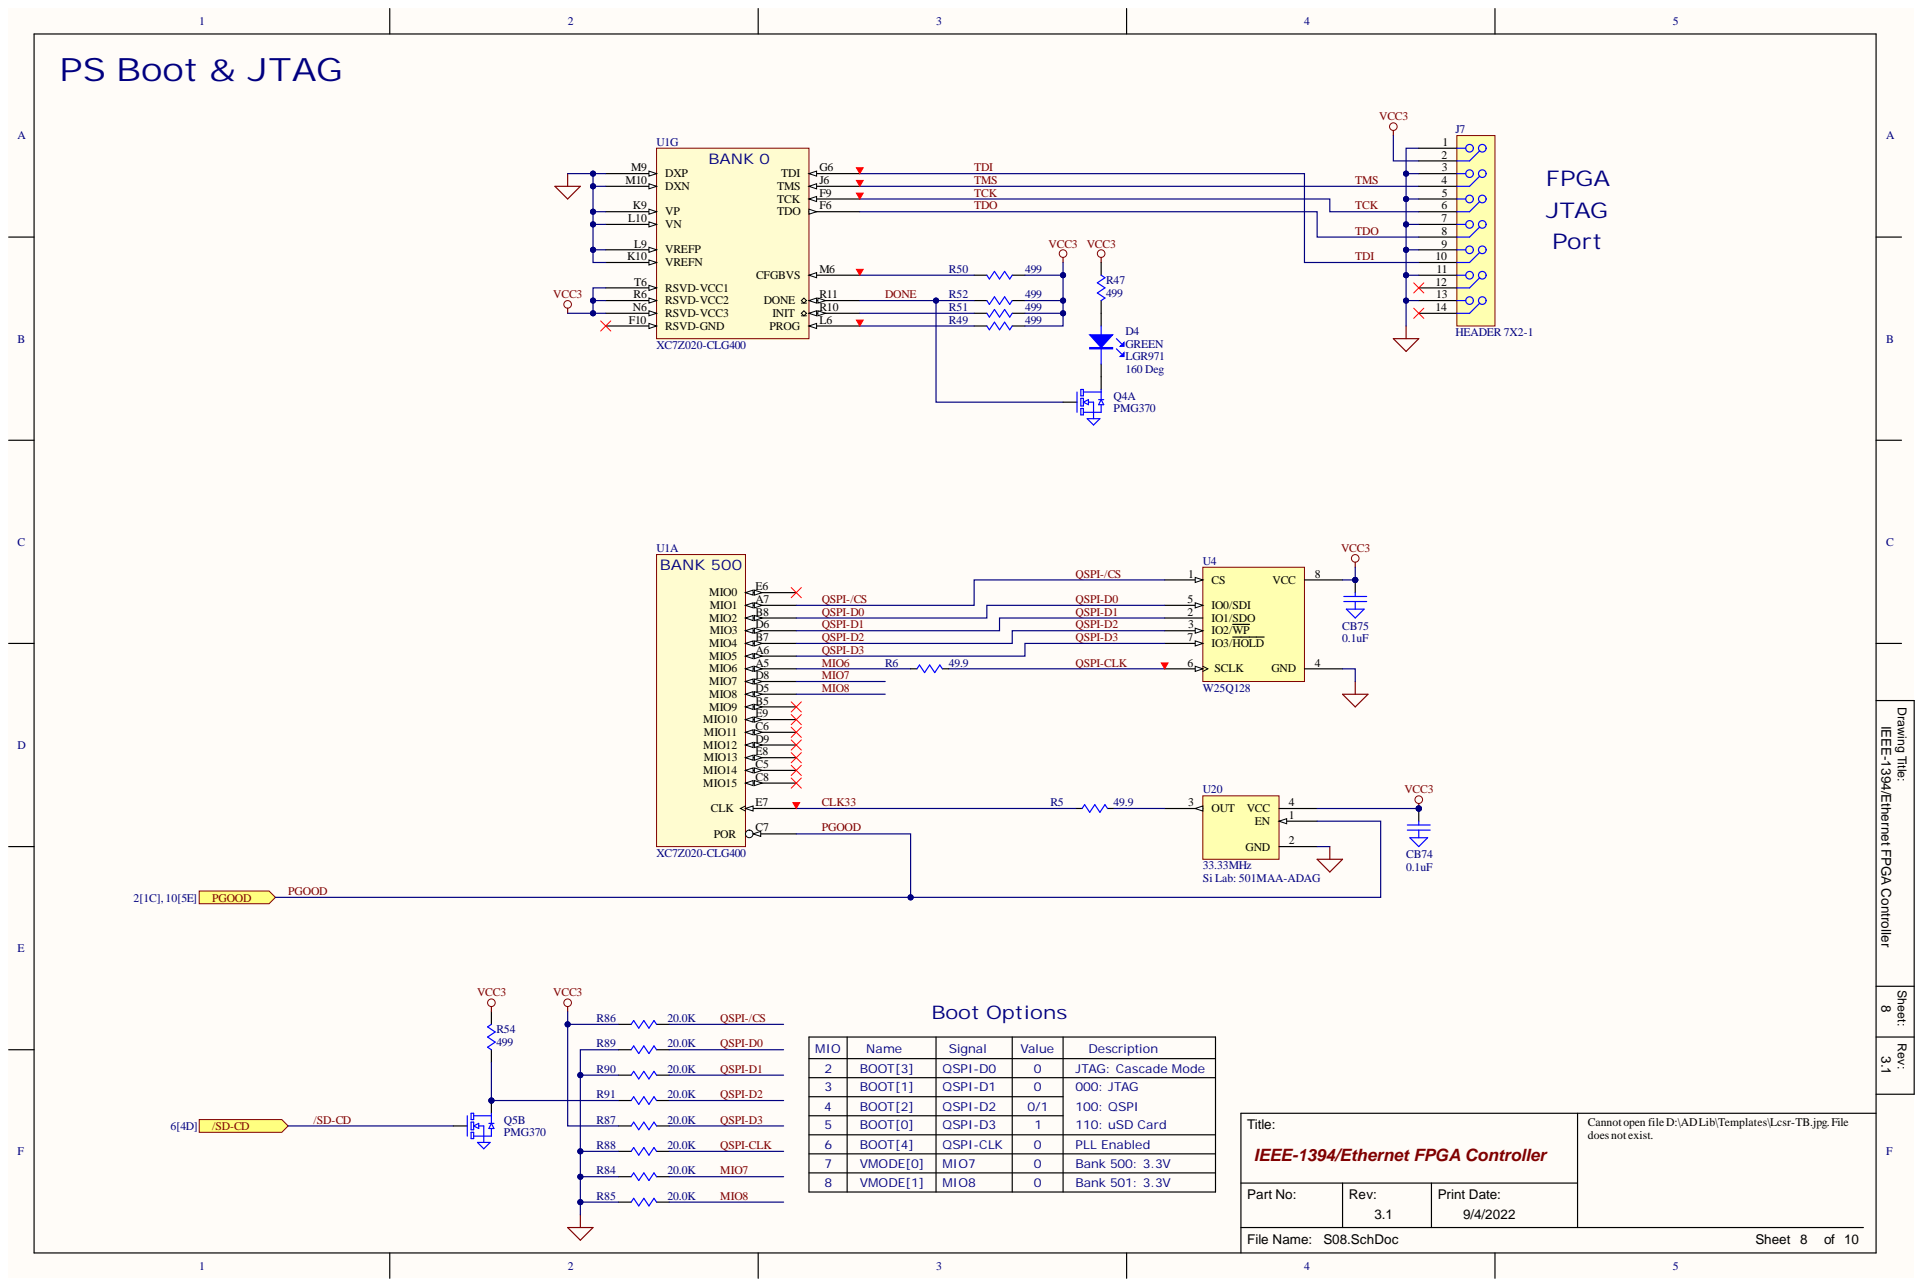
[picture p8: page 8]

VCC3 | 6 7

VREFP L9 | | 8 9

Drawing Title: Rev: Sheet:

8 IEEE-1394/Ethernet FPGA Controller 3.1

MIO | Name | Signal | Value | Description
2 | BOOT[3] | QSPI-D0 | 0 | JTAG: Cascade Mode
3 | BOOT[1] | QSPI-D1 | 0 | 000: JTAG 100: QSPI 110: uSD Card
4 | BOOT[2] | QSPI-D2 | 0/1

Cannot open file D:\ADLib\Templates\Lcsr-TB.jpg. File
does not exist.

Title:
IEEE-1394/Ethernet FPGA Controller

6 | BOOT[4] | QSPI-CLK | 0 | PLL Enabled
7 | VMODE[0] | MIO7 | 0 | Bank 500: 3.3V
8 | VMODE[1] | MIO8 | 0 | Bank 501: 3.3V

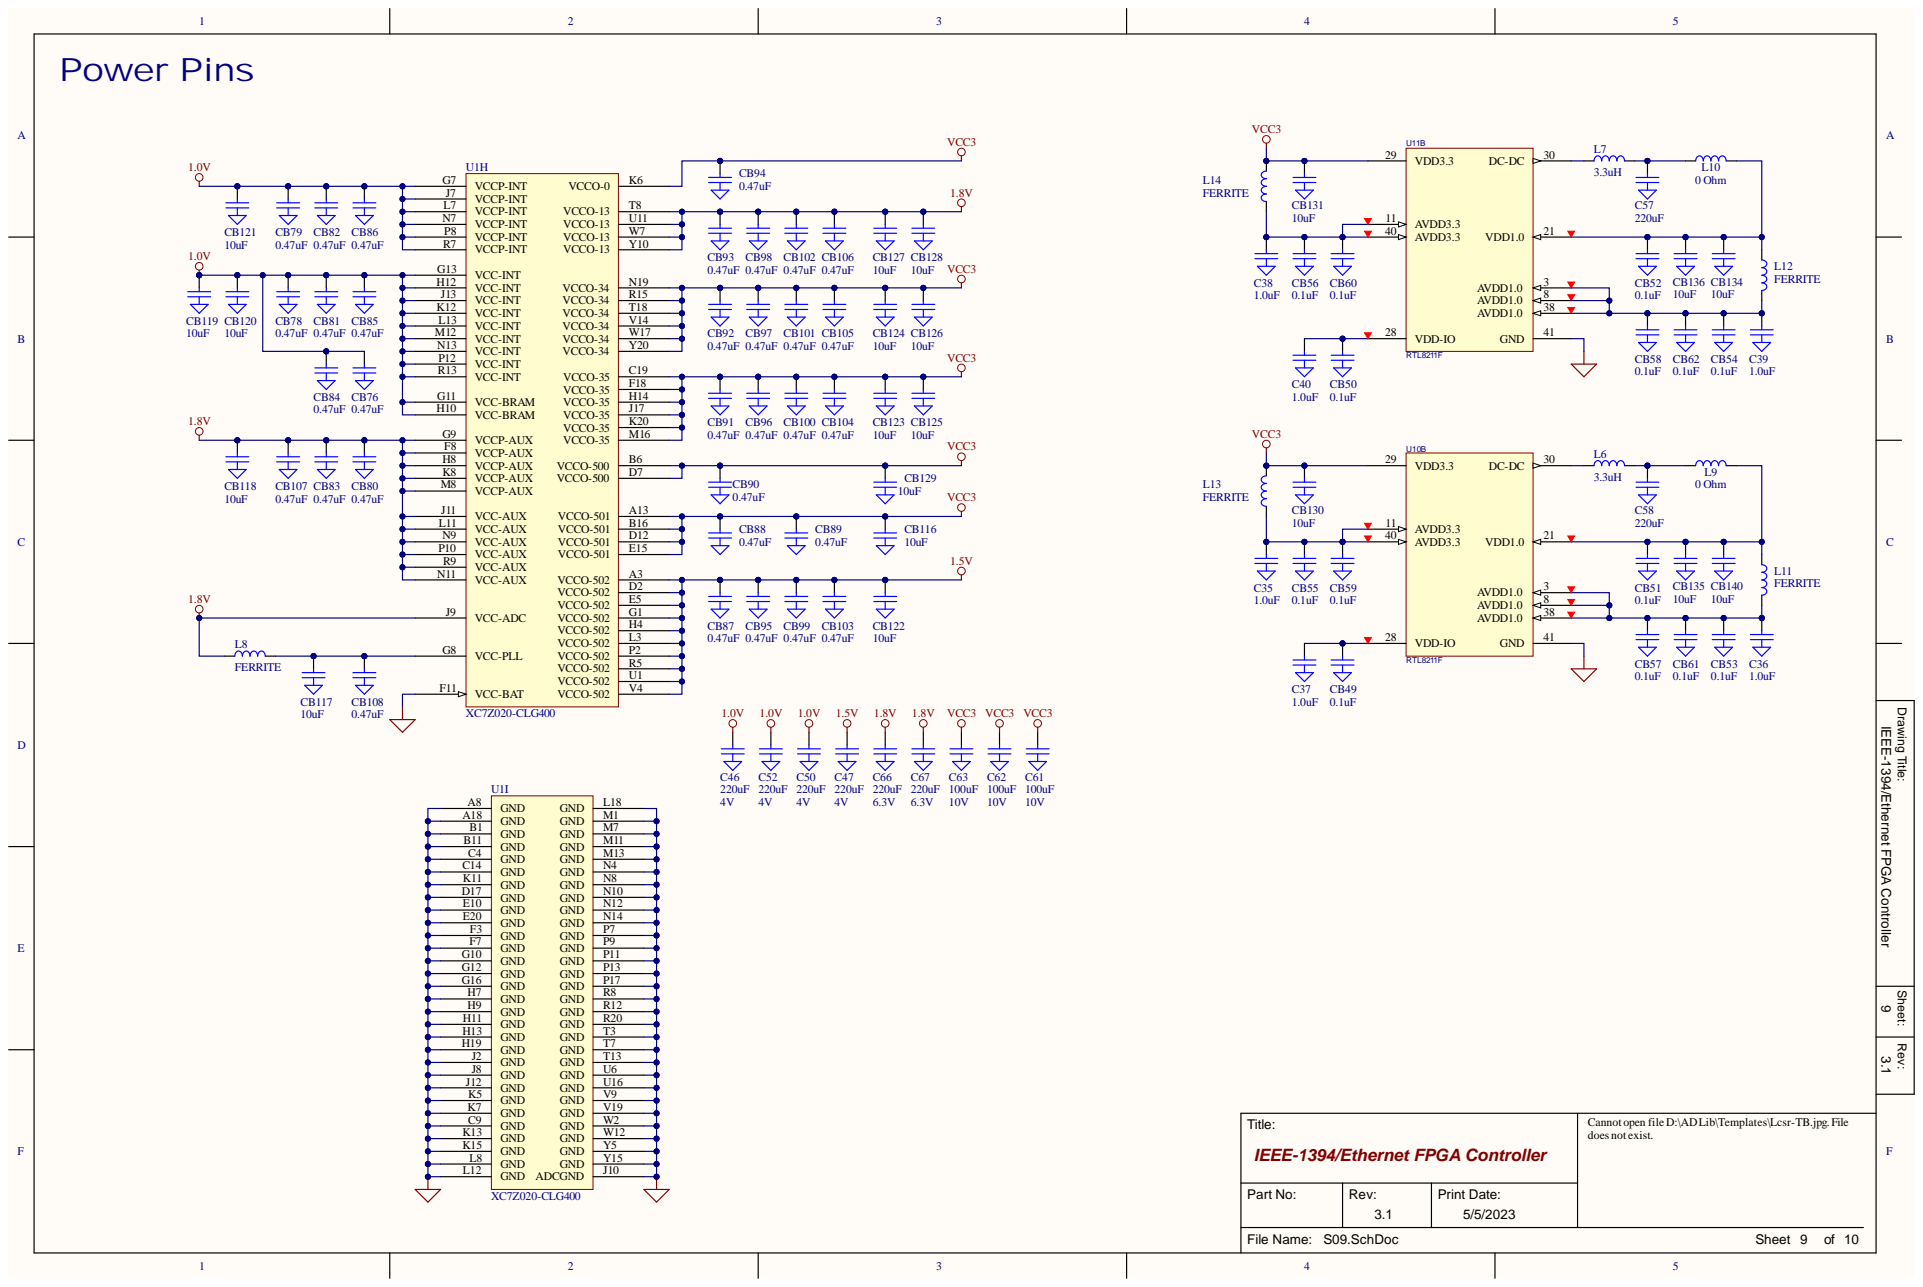
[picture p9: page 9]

VCC-INT P12 | U10B

VCC-BRAM G11 | | VCC3

VCCP-AUX K8 | | CB90 0.47uF | 10uF VCC3
VCCP-AUX M8

VCC-AUX J11

Drawing Title: Rev: Sheet:

9 IEEE-1394/Ethernet FPGA Controller 3.1

Cannot open file D:\ADLib\Templates\Lcsr-TB.jpg. File
does not exist.

Title:
IEEE-1394/Ethernet FPGA Controller

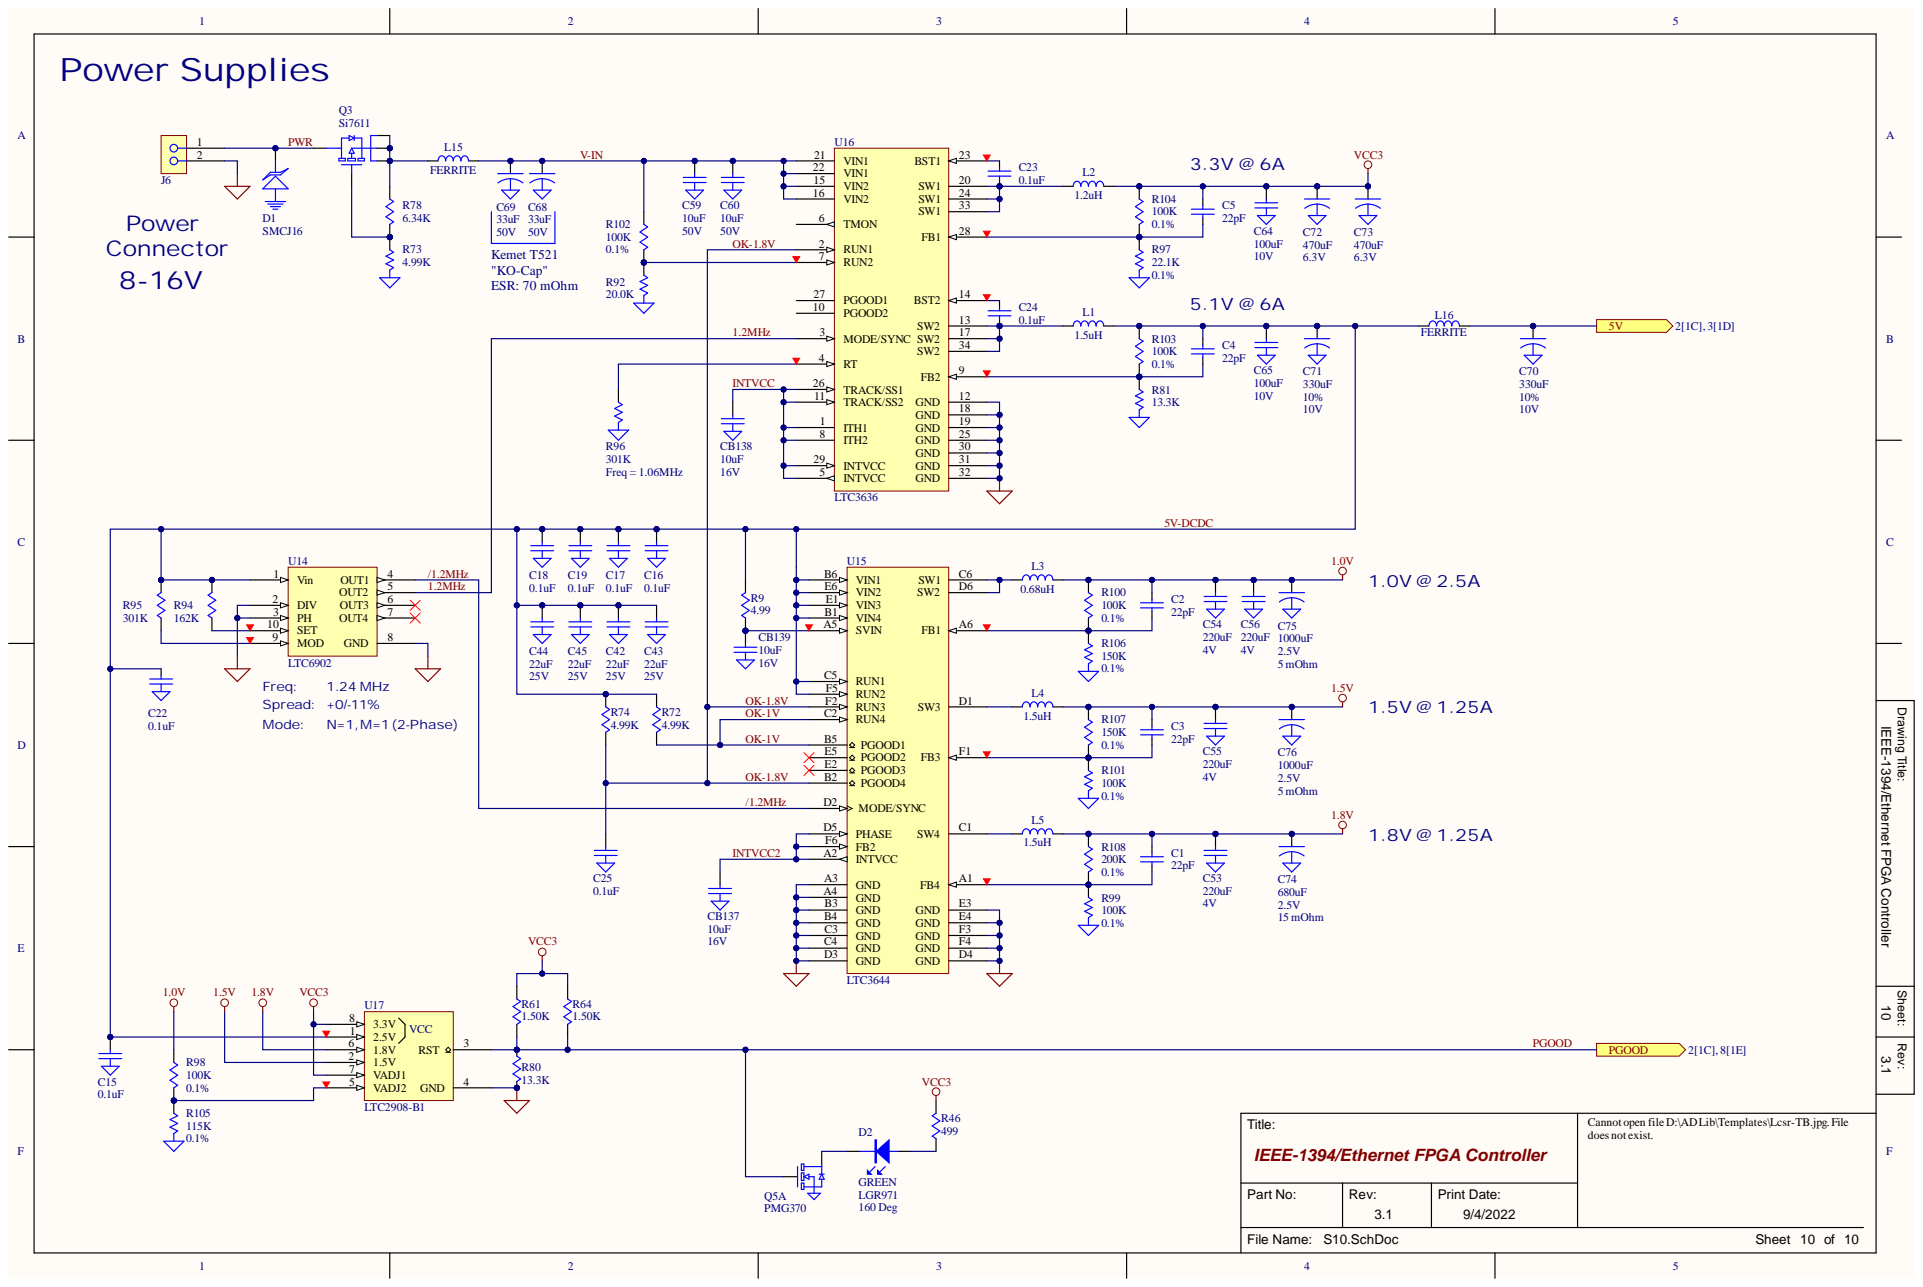
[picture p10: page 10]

INTVCC | TRACK/SS1 26

RUN2 F5

R74 4.99K | RUN4 C2 RUN3 F2

Drawing Title: Rev: Sheet:

10 IEEE-1394/Ethernet FPGA Controller 3.1

OK-1.8V | | PGOOD3 E2 PGOOD2 E5 PGOOD1 B5

VADJ1 7

Cannot open file D:\ADLib\Templates\Lcsr-TB.jpg. File
does not exist.

Title:
IEEE-1394/Ethernet FPGA Controller

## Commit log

2023-01-25 Initial commit (Rev 3.1)
    [FPGA1394V3-BOM.xlsx, FPGA3 Panel.PcbDoc, FPGA3 Panel.PrjPCB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]
2023-05-05 Updated BOM to replace L9-10 by 0 Ohm resistors
    [FPGA1394V3-BOM.xlsx]
2023-05-05 Updated schematics to change L9-10 to 0 Ohm resistors
    [S09.SchDoc]
2024-10-09 Rev 3.2: Removed L9-10, added C77-78, test points on bottom side
    [FPGA1394V3-BOM.xlsx, FPGA3 Panel.PrjPCB, FPGA3.PrjPCB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]
2024-10-09 Replace PDF of schematics (smaller file size)
2024-10-10 Update P/N for Xilinx FPGA to allow -2 or -3 speed grade and any temperature grade
    [FPGA1394V3-BOM.xlsx]
2025-02-23 Corrected U8 part number (had wrong package)
    [FPGA1394V3-BOM.xlsx]
